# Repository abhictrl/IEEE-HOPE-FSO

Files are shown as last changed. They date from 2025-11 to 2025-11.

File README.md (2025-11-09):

# Project Lux: A Free-Space-Optical Audio Link



A laser-based audio communication system built for the Howard University **IEEE H.O.P.E. (Hands-On PCB Engineering)** Project (Fall 2025).

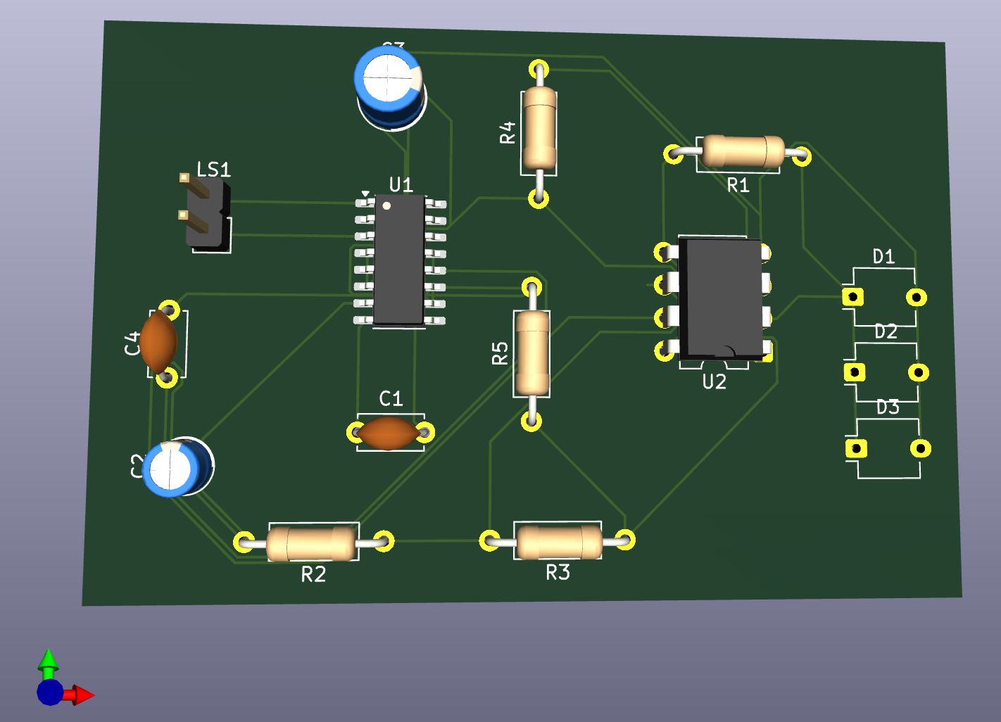
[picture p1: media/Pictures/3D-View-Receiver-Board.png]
Project Lux Receiver Board 3D View


## 🎯 Project Overview

Project Lux is a free-space optical (FSO) communication system that transmits a high-fidelity audio signal over a laser beam.

This project demonstrates the core principles of optical communication. The system consists of two main components:
1.  **The Transmitter:** Modulates an audio signal from a source (like a phone or laptop) onto a laser beam.
2.  **The Receiver:** Intercepts the laser beam, converts the light back into an electrical signal, and amplifies it to drive a speaker.

This creates a simple, point-to-point wireless audio link.

### Key Features
* **Audio Modulation:** An analog circuit modulates a 3.5mm audio input signal onto a laser diode.
* **Optical Detection:** A photodiode array (`BPW34`) detects the modulated laser beam and converts it back into an electrical signal.
* **Custom PCB:** All transmitter and receiver electronics are designed on custom PCBs using KiCad.

## 🛰️ Transmitter Board Design

The transmitter board is the "voice" of the system. Its job is to take a standard audio signal and convert it into a light-based signal by modulating the brightness of a laser.

### 1. Stage 1: Audio Input & Biasing
* **The Problem:** A standard audio (sine) wave is AC, meaning it has a positive and a negative "half." Our single-supply (+5V) circuit can't process negative voltages.
* **The Solution:** A **voltage divider** (`R1`, `R2`) creates a 2.5V "virtual ground." An **AC-coupling capacitor** (`C1`) lets the audio signal "ride" on top of this 2.5V bias, shifting the entire wave into the positive (1.5V to 3.5V) range.

### 2. Stage 2: Voltage-to-Current Conversion (Transconductance)
* **Modulation:** This is the core of the transmitter. It takes the *voltage* signal and converts it into a proportional *current* to drive the laser. This is a **transconductance** stage.
* **The Circuit:** An op-amp (`U1A`) buffers the signal, which then drives a transistor (`Q1`). The transistor acts as a "valve," controlling the current flowing through the laser.
* **Idle Current:** A variable resistor (`R6_Variable`) is used to set the "quiescent" or "idle" current. This keeps the laser on at "half-brightness" when no audio is playing, allowing the signal to modulate both brighter and dimmer.

### 3. Stage 3: Laser Driver
* **Output:** The modulated current from `Q1` drives the laser diode (`LD1`), causing its brightness to flicker in perfect sync with the audio waveform.

## 📡 Receiver Board Design

The receiver board is the "ear" of the system, designed to convert the incoming light signal back into audible sound. The signal path is a three-stage process.

### 1. Stage 1: TIA (Current-to-Voltage)
* **Detection:** An array of `BPW34` photodiodes captures the modulated laser light, generating a tiny electrical current proportional to the light's brightness.
* **Conversion:** The first op-amp (`U2A`) is configured as a **Transimpedance Amplifier (TIA)**. It converts this weak input *current* into a usable *voltage* signal.

### 2. Stage 2: Voltage Pre-Amplification
* **Gain:** The voltage from the TIA is fed into the second op-amp (`U2B`), which is configured as an **inverting gain stage** to boost the signal.

### 3. Stage 3: Power Amplification
* **Coupling:** A `1uF` capacitor (`C2`) blocks the DC component of the signal, passing only the clean AC audio to the final stage.
* **Power Amp:** A `PAM8403D` Class-D audio amplifier takes the line-level signal and provides the necessary power to drive a standard `4S1` speaker.

### Key Components
* **Photodiodes:** `BPW34` (x3)
* **Op-Amp (TIA & Pre-Amp):** `LM358`
* **Power Amplifier:** `PAM8403D`

> **Want more detail?**
>
> Check out the **[Full Circuit Walkthrough](./docs/Circuit-Walkthrough.md)** for a component-by-component explanation of the schematics.

## ⚙️ Tech Stack & Components

### Hardware
* **Audio:** 3.5mm Audio Jacks, PAM8403D Audio Amplifier, Laser Diode
* **Sensors:** BPW34 Photodiodes
* **Circuits:** Op-Amps (LM358), Transistors (2N3904), Passive Components

### Software & Design
* **PCB Design:** KiCad
* **Version Control:** Git & GitHub

## 📂 Repository Structure

This repository is organized to keep our hardware designs, firmware code, and documentation separate and clean.
```
/
├── hardware/
│   ├── Receiver board/     # KiCad project files for the receiver
│   └── Transmitter board/  # KiCad project files for the transmitter
├── firmware/
│   └── ...                 # Arduino C++ source code (coming soon)
├── media/
│   └── pictures
|         └─...                 # Schematics, 3D renders, and demo videos
├── docs/
│   └── Walkthrough.md               # Datasheets, presentations, etc.
├── .gitignore
└── README.md
```
## 📖 Project Status

This project is **currently in progress**.

* [x] Phase 1: Research & Reference (Cornell ECE 4760)
* [x] Phase 2: Initial Circuit Design & Component Sourcing
* [x] Phase 3: Receiver PCB Layout
* [x] Phase 4: Transmitter PCB Layout
* [ ] Phase 5: Final Integration & Testing

## 👥 Team

* Abhishek Rana - Hardware Design (Receiver Board, Transmitter Board)
* Aayush Dahal - Hardware Design (Transmitter Board)
* Diego McCullough - Hardware Design (Power Board)

## 📜 Reference & Inspiration

This project is heavily inspired by the "Laser Audio Transmitter" final project from Cornell University's ECE 4760 course.
* **Link:** [https://people.ece.cornell.edu/land/courses/ece4760/FinalProjects/s2009/dyz2_jl589/dyz2_jl589/index.html](https://people.ece.cornell.edu/land/courses/ece4760/FinalProjects/s2009/dyz2_jl589/dyz2_jl589/index.html)

## 📄 License

This project is licensed under the **MIT License**. See the `LICENSE` file for full details.

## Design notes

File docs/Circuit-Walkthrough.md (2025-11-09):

# Project Lux: Circuit Walkthrough

This document provides a detailed, component-by-component explanation of the transmitter and receiver circuits.

## 🛰️ Transmitter Schematic

Transmitter Schematic
*(You should save your transmitter schematic in `media/pictures/` and update this link)*

The transmitter's function is to convert an audio **voltage** into a modulated **current** to drive a laser. This is a **transconductance** circuit.

### Block 1: Audio Input & DC Biasing
* **`J1` (AudioPlug2):** A 3.5mm audio jack. The 'T' (Tip) pin carries the left audio channel (or mono), which is used as our signal. The 'S' (Sleeve) is ground.
* **`C1` (1uF):** An **AC-coupling capacitor**. It blocks any DC voltage from the audio source, allowing only the AC audio signal (the "music") to pass through.
* **`R1`, `R2` (10k):** These form a **voltage divider**. They take the +5V supply and divide it exactly in half, creating a stable **2.5V DC bias**, or "virtual ground."
* **Function:** The AC signal from `C1` and the 2.5V DC bias from the resistors meet at Pin 3 of the op-amp. This "adds" the two, shifting the audio signal (which swings from ~-1V to +1V) to swing around 2.5V (i.e., from ~1.5V to ~3.5V). This is essential for our single-supply circuit, which cannot process negative voltages.

### Block 2: Amplification & Buffering
* **`U1A` (LM358):** The first op-amp. It's configured as a **non-inverting AC amplifier**.
* **`C2` (10uF) & `R4` (10k):** These components set the AC gain. The gain is $A_v = 1 + (R3 / R4) = 1 + (10k / 10k) = 2$.
* **`R3` (10k):** The feedback resistor. `C2` blocks DC, so for DC signals, the op-amp acts as a voltage follower (gain of 1), which just passes the 2.5V bias through.
* **Function:** This stage amplifies our audio signal by a factor of 2, making it stronger. The output at Pin 1 is a 2.5V DC bias with a twice-as-large AC signal "riding" on it.

### Block 3: The Transconductance Stage (Driver)
* **`R5` (1k):** A current-limiting resistor that connects the op-amp's voltage output to the transistor's "control" pin (the Base).
* **`Q1` (2N3904):** An NPN BJT transistor, which we are using as a **voltage-controlled current source**. It's the "valve" of the circuit. The voltage at its Base (Pin 2) controls how much current it allows to flow from its Collector (Pin 1) to its Emitter (Pin 3).
* **`R7` (39) & `R6_Variable`:** These resistors set the **quiescent (idle) current**. By adjusting `R_Variable`, you set the DC voltage at the emitter, which in turn sets the "baseline" current that flows through the transistor and laser *even when there is no audio*. This is critical for setting the laser to "half-brightness" so the audio signal can make it both brighter and dimmer.

### Block 4: Laser & Protection
* **`LD1` (D6505I):** The laser diode. The current flowing through `Q1` flows through `LD1`, and its brightness is directly proportional to this current.
* **`D1`:** A **flyback diode**. Laser diodes have some inductance and can create a negative voltage spike (flyback) when the current changes fast. This diode gives that spike a safe path to ground, protecting the transistor `Q1` from damage.

### Block 5: Power Supply Decoupling
* **`U1C` (LM358):** This is just the power-pin header for the LM358 chip. Pin 8 is +5V, Pin 4 is GND.
* **`C3` (0.1uF):** A **decoupling (or bypass) capacitor**. It's placed physically close to the op-amp's power pins and acts as a tiny, fast local battery. It filters out high-frequency noise from the power supply, ensuring the op-amp operates stably.

---

## 📡 Receiver Schematic

Receiver Schematic
*(You should save your receiver schematic in `media/pictures/` and update this link)*

The receiver's function is to convert the modulated light **current** from a photodiode back into an audio **voltage**.

### Block 1: Photodetection & TIA Stage
* **`D1`, `D2`, `D3` (BPW34):** These are the photodiodes, connected in parallel to increase the light-sensitive area. When the laser hits them, they generate a small **current** proportional to the light's brightness.
* **`U2A` (LM358) & `R1` (10k):** This is the **Transimpedance Amplifier (TIA)**. Its job is to convert **current-to-voltage**.
* **Function:** The photodiodes dump their current into the op-amp's inverting input (Pin 2), which is a "virtual ground" (held at 0V). The op-amp generates a voltage at its output (Pin 1) to pull that same amount of current through the feedback resistor `R1`. The resulting output is $V_{out} = -I_{photodiode} \cdot R1$. This stage successfully converts the light-current into a voltage.

### Block 2: Biasing & Gain Stage
* **`R3` (5.1k) & `R5` (10k):** This is a **voltage divider** that creates a DC bias of $5V \cdot (10k / (5.1k + 10k)) \approx 3.3V$. This bias is fed to the non-inverting input (Pin 5) of the second op-amp.
* **`U2B` (LM358), `R4` (10k), `R2` (10k):** This is configured as an **inverting gain stage**.
* **Function:** This stage takes the signal from the TIA (fed into `R4`) and amplifies it with a gain of $A_v = -(R2 / R4) = -(10k / 10k) = -1$. The output signal at Pin 7 is centered around the 3.3V bias.

### Block 3: Power Amplifier & Filtering
* **`C2` (1uF):** An **AC-coupling capacitor**. It blocks the ~3.3V DC bias from the `U2B` stage, allowing only the clean, AC audio signal to pass to the power amplifier.
* **`U1` (PAM8403):** A 3W, Class-D stereo audio amplifier.
    * `INL` (Pin 7): The Left audio input, which receives our signal from `C2`.
    * `SHDN` (Pin 1) & `MUTE` (Pin 10): Shutdown and Mute pins. They are tied to the `VREF` pin, which (along with `C1`) sets them to an "enabled" state.
* **`C3` (20uF) & `C4` (0.1uF):** Power supply filtering and decoupling capacitors for the `PAM8403`. `C3` is the bulk capacitor to handle large current draws, and `C4` filters high-frequency noise.
* **`4S1` (speaker):** The 4-ohm speaker, connected to the Left differential output (`LOUT+` and `LOUT-`).
* **`U2C` (LM358):** The power pins (Pin 8 = +5V, Pin 4 = GND) for the LM358 op-amp chip.

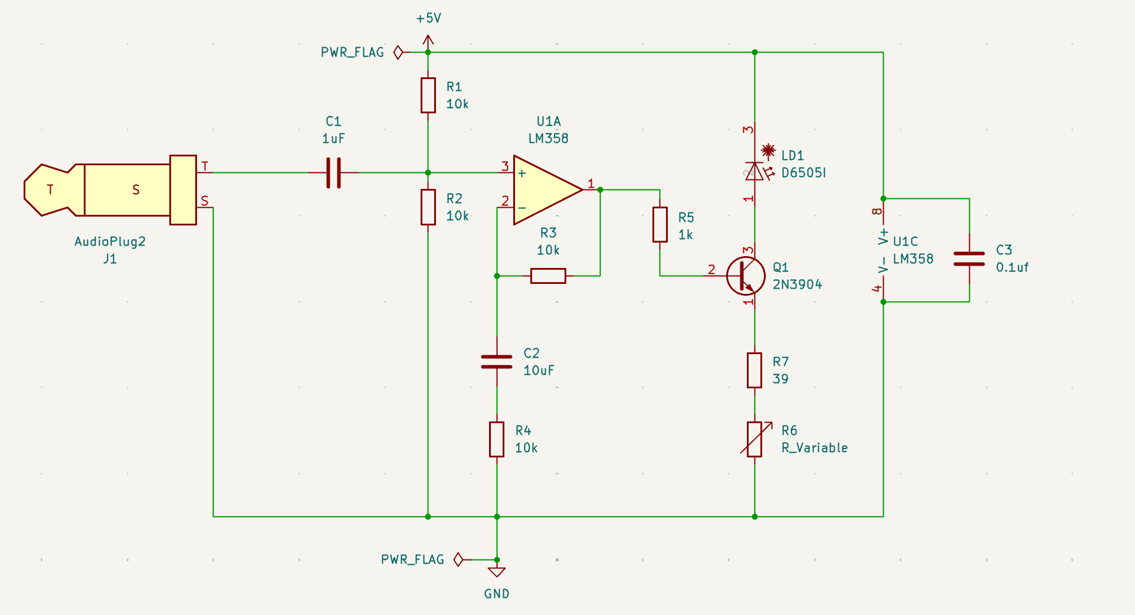
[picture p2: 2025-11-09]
media/Pictures/Transmitter_Schematic(OTA).png

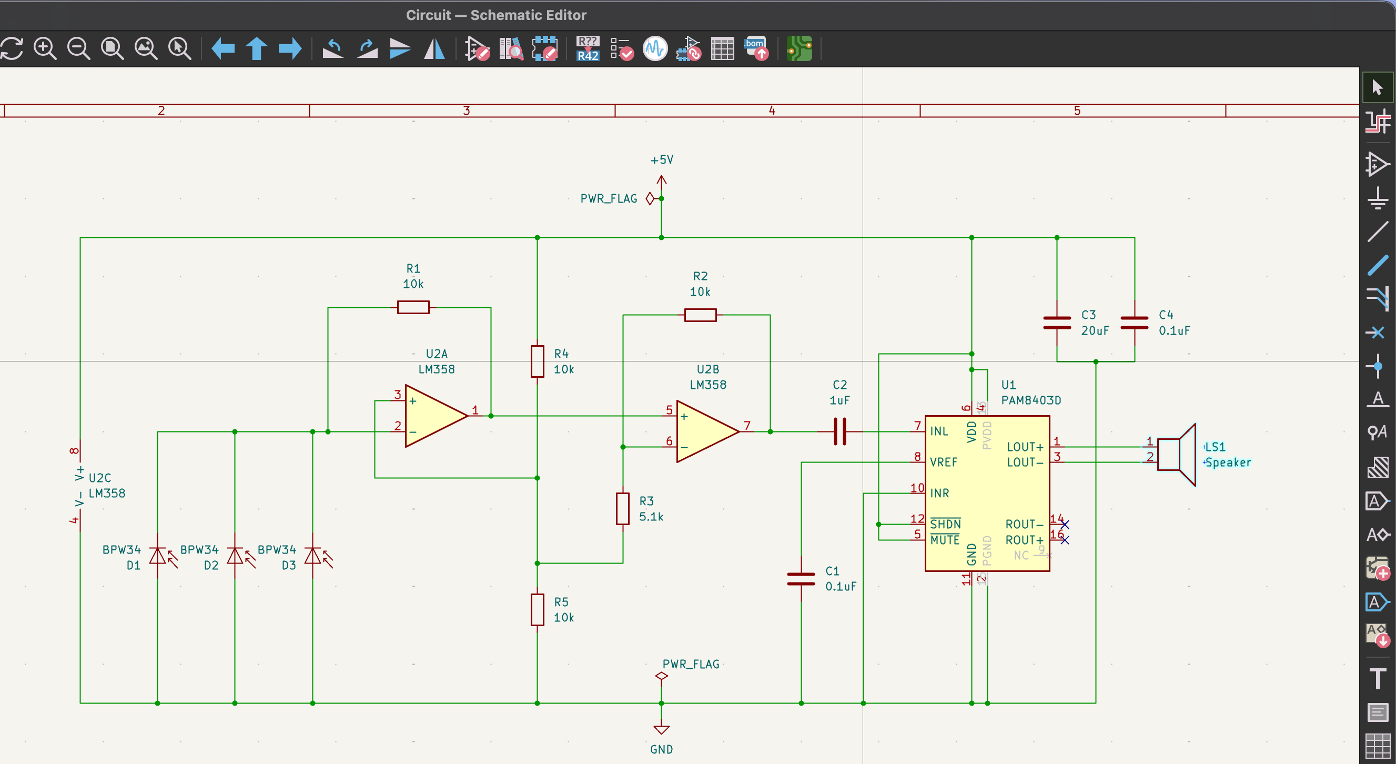
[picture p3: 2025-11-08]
media/Pictures/Schematic-Receiver(TIA).png

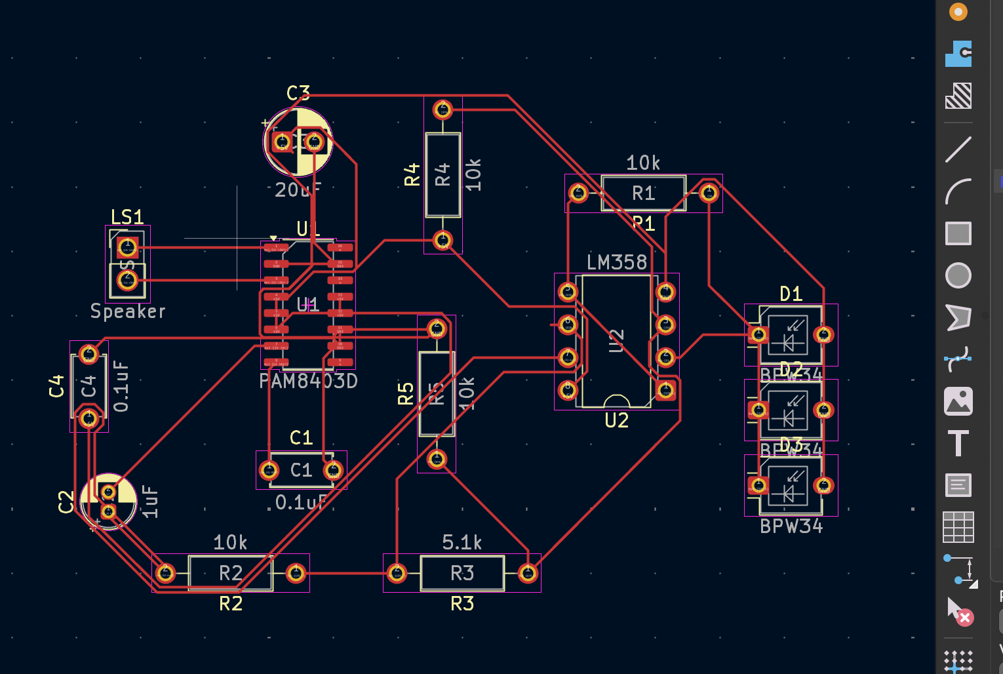
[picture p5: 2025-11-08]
media/Pictures/Layout Receiver updated.png

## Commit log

2025-10-31 Added initial receiver board design and 3d images)
    [Circuit.kicad_pcb, Circuit.kicad_sch]
2025-11-04 Made Schematic for Reciever Board more Readable
    [Circuit.kicad_pcb, Circuit.kicad_sch]
2025-11-04 Schematic view pic updated
2025-11-04 Updated Reciever Board
    [Circuit.kicad_pcb, Circuit.kicad_sch]
2025-11-08 Updated Schematic for Receiver: TIA with virtual ground for Op-Amps for handling negative half of the signal
    [Circuit.kicad_pcb, Circuit.kicad_sch]
2025-11-08 Schematic pic
2025-11-08 Layout updated after the Schematic update
    [Circuit.kicad_pcb]
2025-11-09 Completed the Schematic for Transmitter Board
    [proejtc.kicad_sch]
2025-11-09 Transmitter Schematic
    [proejtc.kicad_sch]
2025-11-09 Schematic pic of transmitter
2025-11-09 Added Circuit-Walkthrough file
2025-11-12 fixed biasing of laser diode
    [proejtc.kicad_sch]

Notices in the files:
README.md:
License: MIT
